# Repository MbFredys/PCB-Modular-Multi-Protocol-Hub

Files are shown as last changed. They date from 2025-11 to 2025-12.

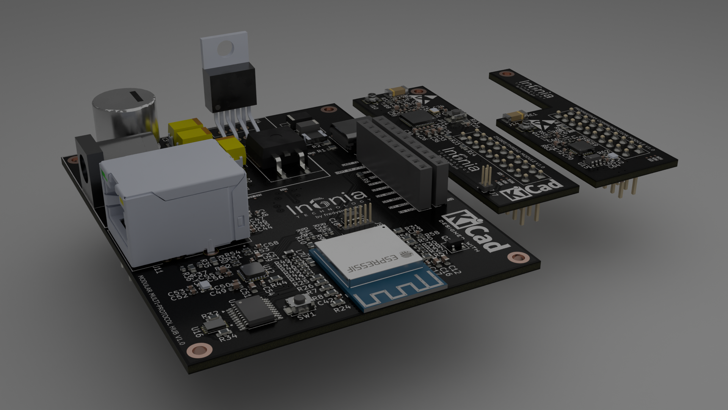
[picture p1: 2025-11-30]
Release/HUB-3D.png

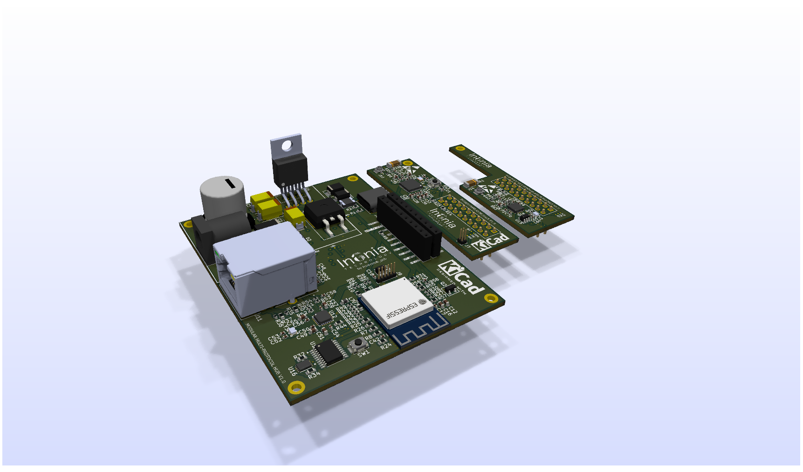
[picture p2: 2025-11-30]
Release/Hub3-pro.png

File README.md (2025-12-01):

# ⚡ Universal Smart-Home Modular Hub  


A compact, scalable, multi-protocol communication platform designed for modern smart homes.  
Built around a powerful **ESP32-S3**, with plug-in radio modules for Zigbee/Thread and Proprietary RF.  
Reliable power architecture, clean RF design, and automatic module detection.

---

## 🌍 Overview  
This system uses a **three-board modular hub architecture**:

### **1) Main Board – ESP32-S3 Controller**
Contains the ESP32-S3 with native **Wi-Fi + Bluetooth LE**, full power management, Ethernet support, and the universal expansion bus.

### **2) Zigbee/Thread Module – EFR32MG24**
A dedicated 2.4 GHz radio module supporting **Zigbee**, **Thread**, and **Matter over Thread** with a high-efficiency antenna.

### **3) Proprietary RF Module – nRF24L01+**
A flexible low-power 2.4 GHz module for **custom protocols**, legacy devices, and private links.

⚠️ **Only one expansion module is active at a time.**  
The **Main Board can run standalone** using Wi-Fi and BLE even with no module attached.

---

## 🎯 Problem This Project Solves  
Most smart-home hubs are:

- Locked to one brand or protocol  
- Difficult to expand  
- Closed hardware  
- Not modifiable or repairable  
- Dependent on cloud services  
- Not designed for RF noise isolation  

This project solves these issues with a fully documented, open, modular, serviceable platform.

---

# 🚀 Main Features

---

## 🧠 Main Board – ESP32-S3 Core Controller  

### **Capabilities**
- Native Wi-Fi + BLE  
- USB programming  
- JTAG debugging  
- I²C bus for module identification  
- SPI bus shared with expansion modules  
- Presence-detect signal  
- Ethernet PHY  
- Local battery backup  
- Clean, isolated power rails  

### **Standalone Operation**
If no radio module is plugged in, the board still supports:

- Wi-Fi control  
- BLE provisioning  
- Local automation  
- OTA updates  

---

## 📡 Zigbee / Thread / Matter Module – EFR32MG24  

### **Capabilities**
- Zigbee 3.0  
- Thread 1.3  
- Matter over Thread  
- High-efficiency chip antenna or external u.FL  
- SPI + IRQ communication  
- Local low-noise LDO  
- EEPROM with module ID  
- Hardware reset & enable control  
- SWD header for development  

### **Why a Separate Board?**
- RF noise isolation  
- Easy upgrades  
- Thermal and EMI improvements  
- Lower main-board complexity  

---

## 📡 Proprietary RF Module – nRF24L01+  

### **Capabilities**
- 2.4 GHz bidirectional transceiver  
- SPI interface  
- IRQ line  
- CE line for TX/RX control  
- Local LDO for clean RF power  
- On-board EEPROM for identification  

### **Why It Exists**
- Legacy systems  
- Private, encrypted links  
- Ultra-low-power sensors  
- Custom protocols  

---

# 🔋 Power Architecture

### **Main Board**
- 12 V input  
- Step-down to 5 V  
- 3.3 V LDO for logic  
- Local LDOs for each RF module  
- Battery charger & backup  
- Inrush, surge, ESD protection  
- Proper decoupling everywhere  

### **Radio Modules**
- Dedicated LDO  
- Ferrite-bead power filtering  
- Enable pin for power control  
- RF-clean power domain  

---

# 🧩 Automatic Module Identification (EEPROM)

Every expansion module includes a **24AA02E48 EEPROM** that stores:

- Unique EUI-48  
- Module type ID  

The ESP32 reads the EEPROM via I²C on boot and:

1. Identifies the module type  
2. Powers only the selected module  
3. Loads the appropriate firmware configuration  

---

# 🛡️ Reliability & Safety

- TVS on power rails  
- ESD protection on connectors  
- Solid ground planes  
- RF-clean routing  
- Ferrite-bead domain separation  
- Reverse-polarity protection  
- Controlled RF impedance paths  

---

# 🧭 Why This Architecture Is Better

- **Fully modular** — plug-in radio modules  
- **Upgradable** — replace modules anytime  
- **Main board works standalone**  
- **Automatic detection** via EEPROM  
- **Clean RF design** with isolated power  
- **Open hardware**  
- **Supports Wi-Fi, BLE, Zigbee, Thread, Matter, Proprietary RF**  
- **Future-proof** platform  
- **Easy to manufacture & repair**  

---

# 🛠️ Usage

1. Power the Main Board with 12 V  
2. Plug in a Zigbee or Proprietary RF module  
3. Firmware reads the module EEPROM  
4. Selected module is powered via EN_LDO  
5. ESP32 configures SPI/I²C pins  
6. Start using the hub via Wi-Fi, BLE, or RF  

---

# 🚀 Getting Started

1. Download design files  
2. Open schematic and PCB in KiCad  
3. Review:
   - Power sections  
   - Module connector  
   - RF networks  
   - Decoupling and filtering  
4. Manufacture PCBs  
5. Assembly order:
   1. Power stage  
   2. ESP32-S3 main board  
   3. Expansion connectors  
   4. RF module components  
   5. Antennas  
6. Flash the ESP32-S3 via USB  
7. Flash EFR32 module via SWD (if needed)  
8. Test and integrate with your smart-home backend  

---

# 🪪 License  
This project is licensed under the CERN Open Hardware Licence Version 2 - Weakly Reciprocal (CERN-OHL-W-2.0).
See the [CERN-OHL-W-2.0 ↗](https://gitlab.com/ohwr/project/cernohl/-/wikis/uploads/82b567f43ce515395f7ddbfbad7a8806/cern_ohl_w_v2.txt) file for more information.

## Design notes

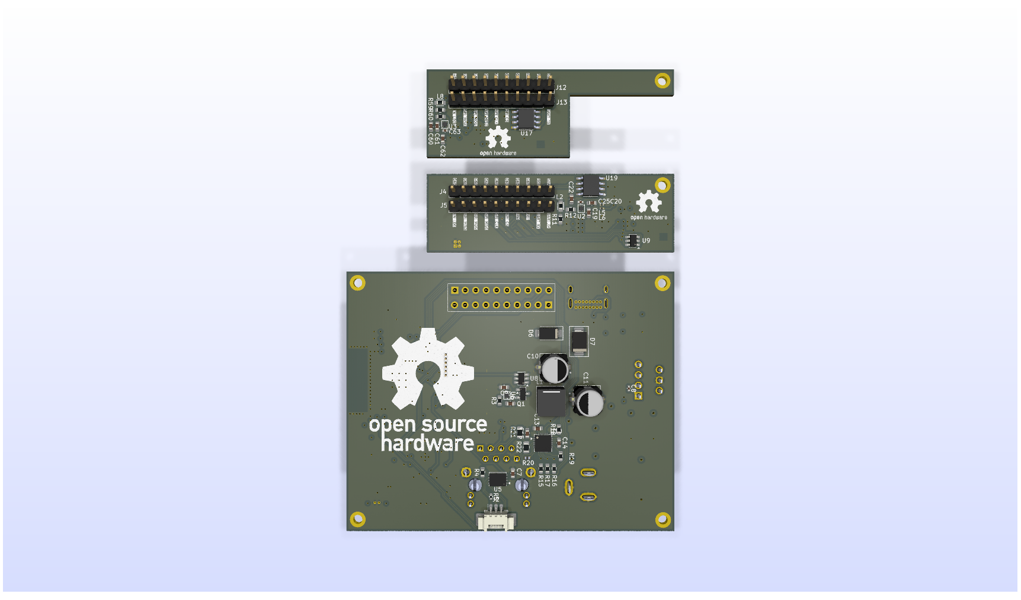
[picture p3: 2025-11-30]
Release/Hub2.png

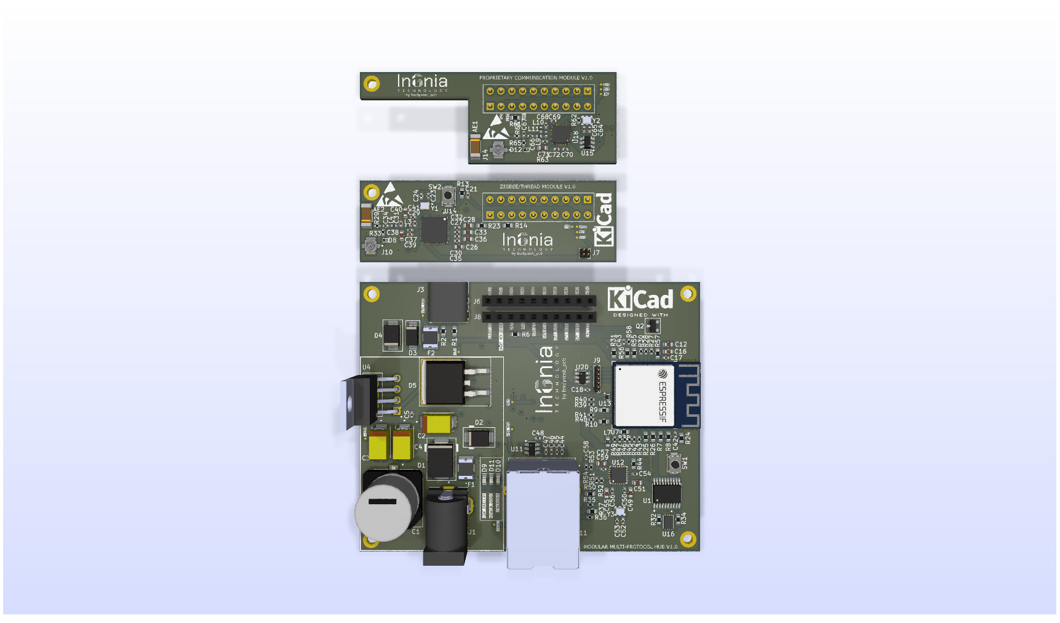
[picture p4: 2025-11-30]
Release/Hub1.png

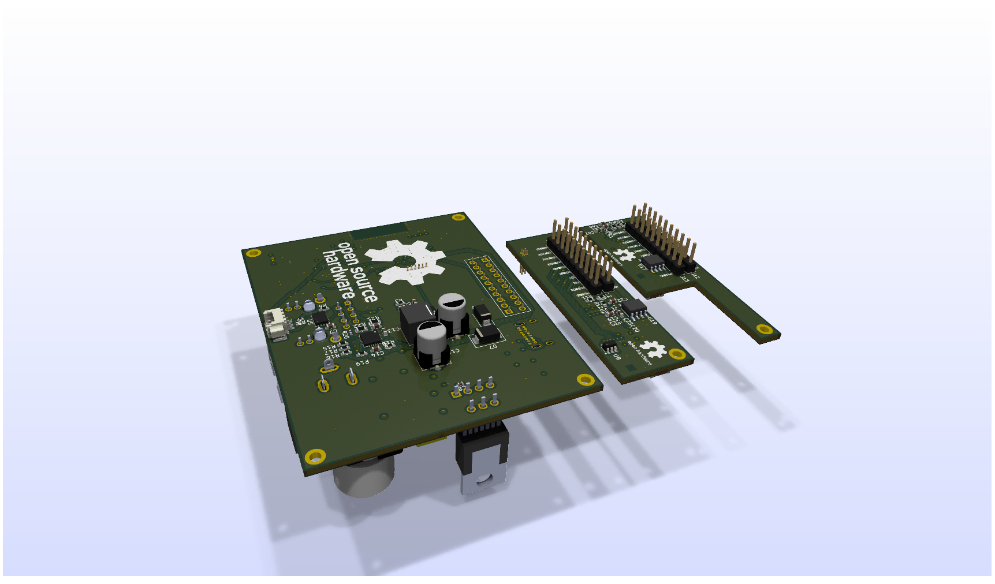
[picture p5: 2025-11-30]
Release/Hub4-pro.png

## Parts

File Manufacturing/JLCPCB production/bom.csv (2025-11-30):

Designator | Footprint | Quantity | Value | LCSC Part #
_6, _5, _4, _3, _2, |  | 6
+12V, +5V, +5V SYS, +5V USB, +VBAT, 3V3_3, 3V3_2, 3V3, GND_2, GND, IRQ_2, IRQ, NRST | TestPoint-0.5mm | 13 | 0.5mm
AE1, AE2 | ANT_2450AT42A100E_JOT | 2 | 2450AT42A100E | C2917719
C1 | CAP_EEVFK1E102Q | 1 | 1000uF | C178725
C10, C11 | CAP_EEEFNE181XUV | 2 | 180uF | C540948
C12, C51 | 0603 | 2 | 10uF | C48579265
C13, C16, C20, C22, C26, C28, C33, C36, C38, C49, C55, C57, C6, C61, C62, C7, C9 | 0603 | 17 | 1uF | C15849
C14, C15 | 0603 | 2 | 4.7uF | C1705
C17, C18, C21, C25, C27, C30, C32, C42, C43, C48, C54, C58, C63 | 0402 | 13 | 0.1uF | C48579249
C19, C60 | 0603 | 2 | 10uF | C15849
C2, C3, C4 | CAPPM7343X310N | 3 | 15uF | C382110
C23, C24, C44, C45, C46, C47, C52, C53 | 0402 | 8 | 10pF | C106199
C29 | 0402 | 1 | 2.3pF | C2220993
C31 | 0402 | 1 | 1.6pF | C161311
C34, C41 | 0402 | 2 | 18pF | C106202
C35, C69, C71 | 0402 | 3 | 10nF | CL05B103KB5NNNC
C37 | 0402 | 1 | 0.47uF | C92361
C39 | 0402 | 1 | 120pF | C106996
C40 | 0603 | 1 | 2.2uF | C48579298
C5 | 0402 | 1 | 0.47uF | C471404
C50, C59 | 0402 | 2 | 470pF | C76971
C56 | 0402 | 1 | 470pF
C64, C65 | 0402 | 2 | 22pF | C76960
C66 | 0402 | 1 | 1.5pF | C76901
C67 | 0402 | 1 | 1pF | C76898
C68, C70 | 0402 | 2 | 33nF | C7419416
C72 | 0402 | 1 | 1nF | C77018
C8 | 0402 | 1 | 0.01uF | C5137480
D1 | D_SMC | 1 | SS54 | C22452
D10, D11, D9 | 0603 | 3 | LEDs | C19171301
D12, D8 | D_SOD-923 | 2 | ESD9B3.3ST5G | C96512
D2 | D_SMB | 1 | SMBJ12A | C151251
D3, D6 | D_SMA | 2 | SS14 | C2837270
D4, D7 | D_SMB_TVS | 2 | SMBJ5.0CA | C5331095
D5 | TO-263-2_TabPin1 | 1 | MBRB735 | C6604203
F1, F2 | FUSE_1812L05060_LTF | 2 | PTC_FUSE | C163516
J1 | MPD_EJ503A | 1 | CON_12VDC_IN | C3095117
J10, J14 | LINX_CONMHF1-SMD-G-T | 2 | CONMHF1 | C22442695
J11 | ABRACON_ARJM11D7-009-AB-EW2 | 1 | ARJM11D7-009-AB-EW2 | C3179097
J12, J13 | PinHeader_1x10_P2.54mm_Vertical | 2 | PINHD
J2 | Molex_PicoBlade_53261-0371_1x03-1MP_P1.25mm_Horizontal | 1 | Conn_BAT | C293630
J3 | USB_C_Receptacle_GCT_USB4085 | 1 | Conn_USB_C | C7095263
J4, J5 | PinHeader_1x10_P2.54mm_Vertical | 2 | PINHD | C492409
J6, J8 | PinSocket_1x10_P2.54mm_Vertical | 2 | PINHD | C5444407
J7 | PinHeader_2x02_P1.00mm_Vertical | 1 | PINHD | C225517
J9 | PinHeader_1x06_P1.00mm_Vertical | 1 | JTAG | C52016393
L1 | IND_XAL6060-223MEB | 1 | 22uH | C475917
L10 | 0402 | 1 | 8.2nH | C84404
L11 | 0402 | 1 | 2.7nH | C162541
L2, L8 | R_0603 | 2 | FerriteBead_0603_1.5A | C2442094
L3 | 0402 | 1 | 2.5nH | C237342
L4 | 0402 | 1 | 1.7nH | C237342
L5, L6 | 0201 | 2 | FerriteBead_0603_1.5A | C97850
L7 | 0603 | 1 | FerriteBead | C14709
L9 | 0402 | 1 | 3.9nH | C98062
Q1 | SOT-23 | 1 | FDN340P | C75469
Q2 | SOT-23 | 1 | BC817 | C609806
R1, R2 | 0603 | 2 | 5.1k | C2907114
R10, R12, R13, R14, R24, R37, R4, R44, R55, R56, R57, R60, R8, R9 | 0603 | 14 | 10k | C2906982
R11, R3, R59, R6 | 0603 | 4 | 100k | C2906980
R15, R16, R17, R18, R19, R7 | 0603 | 6 | 470k | C2930293
R20 | THRMC1005X55N | 1 | 10k | C17294780
R21 | 0805 | 1 | 330k | C2907257
R22 | 0805 | 1 | 110k | C2907221
R23, R31 | 0603 | 2 | 1K | C49196685
R25, R26, R32, R34 | 0603 | 4 | 4.7k | C2907034
R27, R28, R30 | 0402 | 3 | 22 | C2929994
R29, R33, R64, R65 | 0402 | 4 | 0 | C106231
R38 | 0603 | 1 | 2.2k | C114662
R39, R40, R41, R42, R43, R45, R46, R47, R48, R49 | 0402 | 10 | 33 | C2906868
R5, R58 | 0402 | 2 | 100 | C2906860
R50 | 0603 | 1 | 12.1k | C2930059
R51, R52, R53, R54 | 0402 | 4 | 50 | C853312
R61 | 0603 | 1 | 10k
R62 | 0402 | 1 | 1M | C138033
R63 | 0603 | 1 | 22k | C2907015
SW1, SW2 | SW_Push_SPST_NO_Alps_SKRK | 2 | uC_Reset | C115357
U1 | TSSOP-20_4.4x6.5mm_P0.65mm | 1 | TCA9544A | C2674619
U10 | QFN-20-1EP_4x4mm_P0.5mm_EP2.5x2.5mm | 1 | MCP73871 | C5121473
U11 | SOT-23-6 | 1 | WE-TVS-824015043 | 824015043
U12 | LAN8720A | 1 | LAN8720A | C17146
U13 | Texas_DRT-3 | 1 | TPD2EUSB30A | C94934
U14 | XCVR_EFR32MG24B310F1536IM48-B | 1 | EFR32MG24B310F1536IM48-B | C6033379
U15, U20, U9 | SOT-23-6 | 3 | WE-TVS-824015043
U16 | SON50P200X300X60-9N | 1 | ATECC608A-MAHDA-T | C4749250
U17, U19 | SOIC127P600X175-8N | 2 | 24AA02E48-I_SN | C81475
U18 | QFN50P400X400X95-21N | 1 | NRF24L01 | C7015539
U2, U3, U6 | Texas_X2SON-4_1x1mm_P0.65mm | 3 | TPS7A20xxxDQN | C2866482
U4 | TO127P1041X469X2199-7N | 1 | LM2678T-ADJ | C95178
U5 | WDFN-8-1EP_4x3mm_P0.65mm_EP2.4x1.8mm | 1 | LC709203FQH-01TWG | C152311
U7 | ESP32-MINI | 1 | ESP32-S3-MINI-1 | C2913206
U8 | TSOT-23-6 | 1 | LTC4412xS6 | C514442
Y1 | XTAL_ECS-390-CDX-1932 | 1 | 39MHz | C19858547
Y2 | Crystal_SMD_2.0x1.6mm | 1 | 16MHz | C1985805
Y3 | Crystal_SMD_2.0x1.6mm | 1 | 25MHz | C1985948

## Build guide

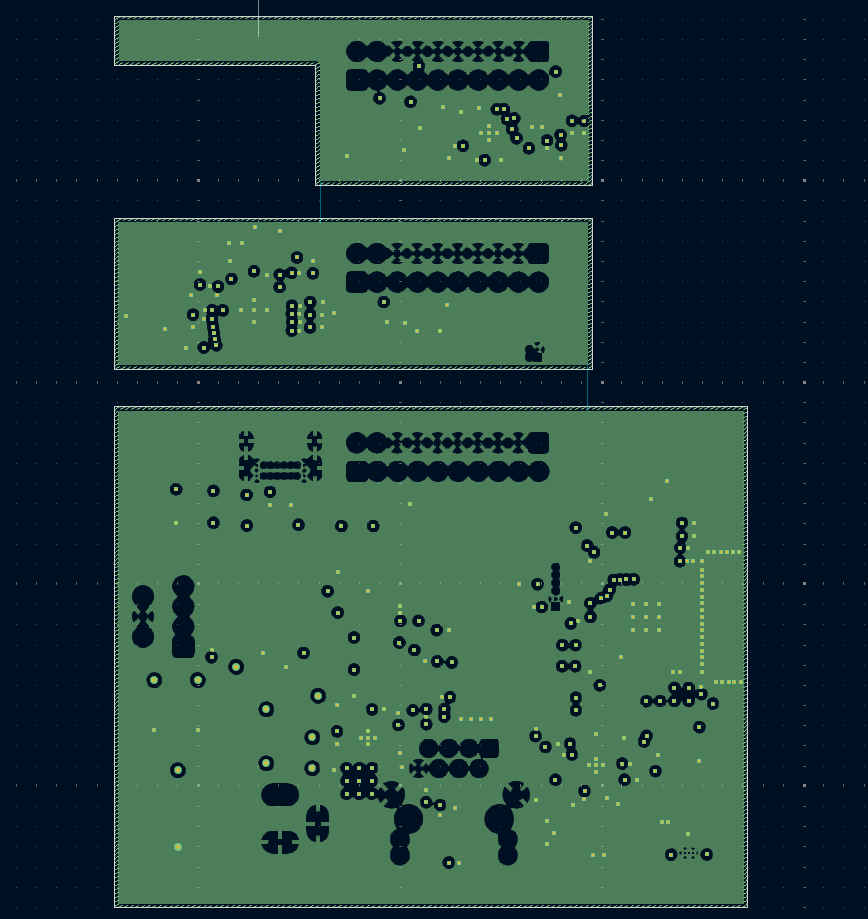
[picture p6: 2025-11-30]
Manufacturing/2nd Layer.png

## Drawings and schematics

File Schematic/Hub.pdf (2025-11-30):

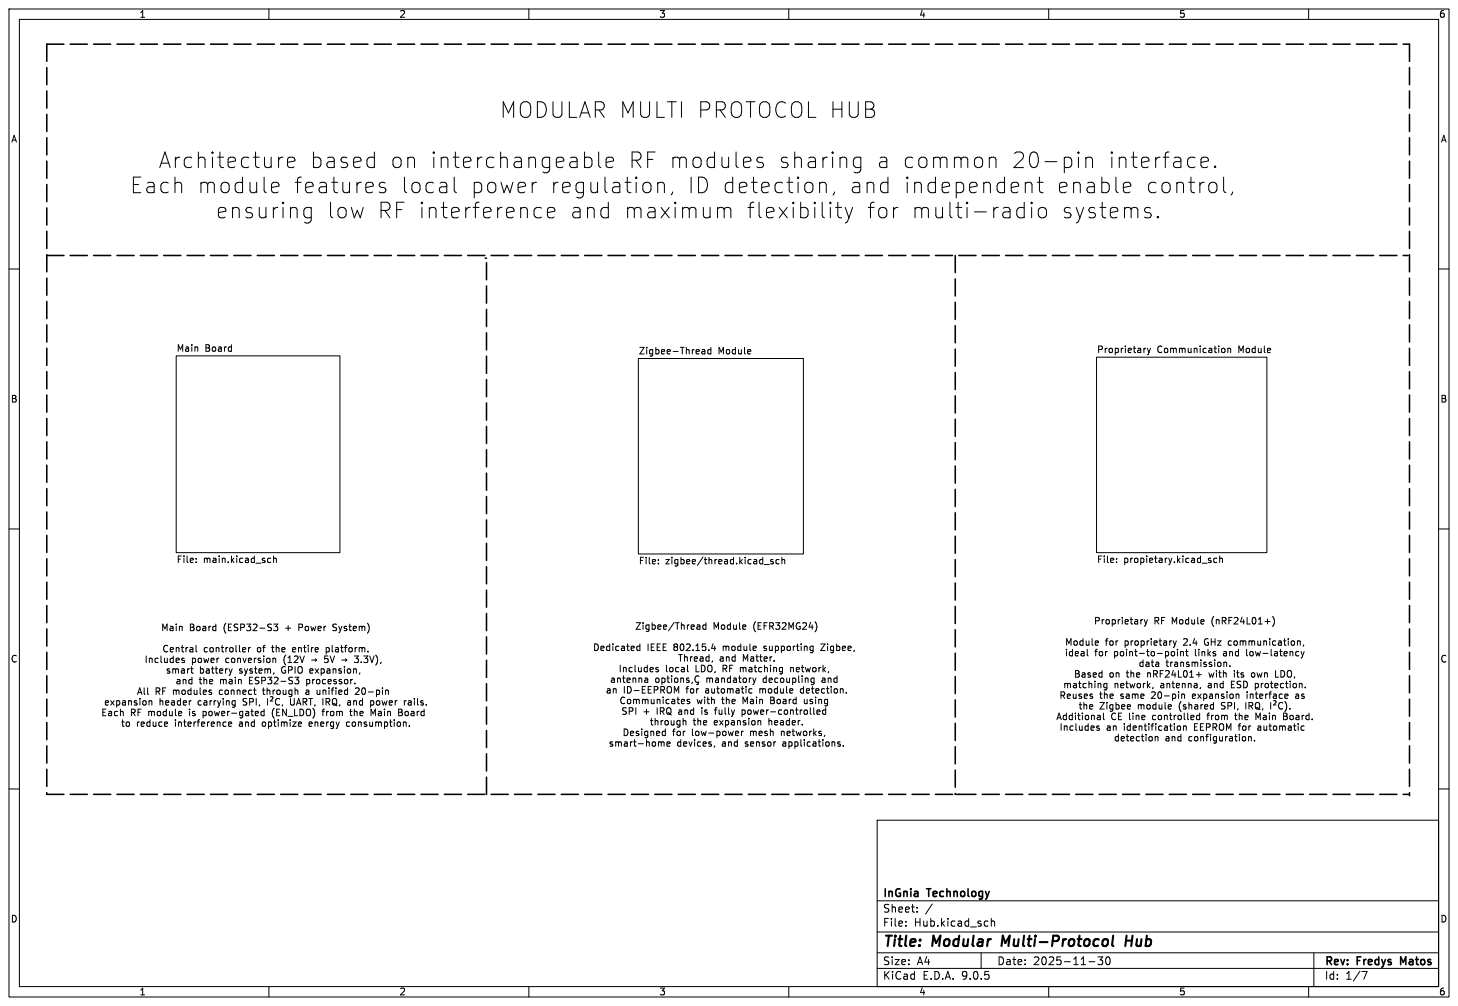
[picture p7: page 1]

MODULAR MULTI PROTOCOL HUB

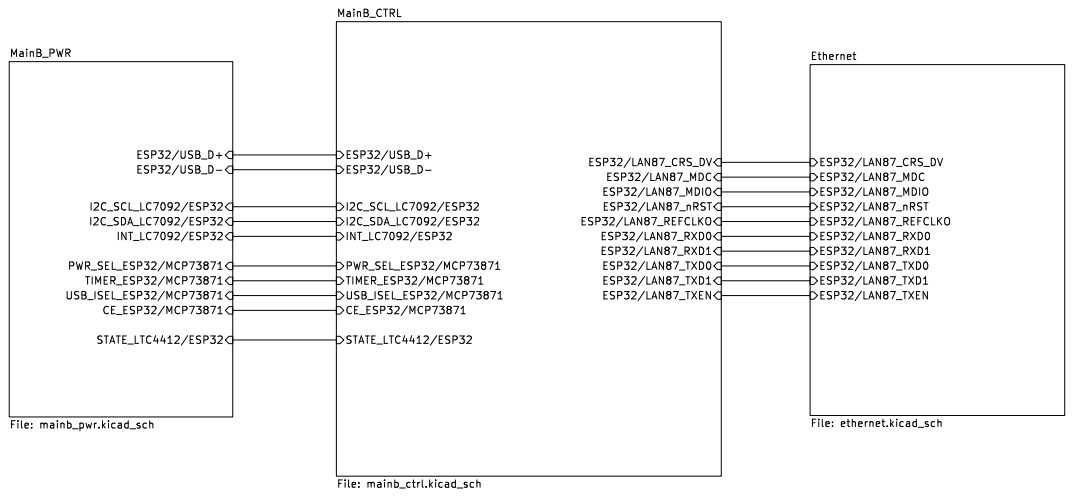
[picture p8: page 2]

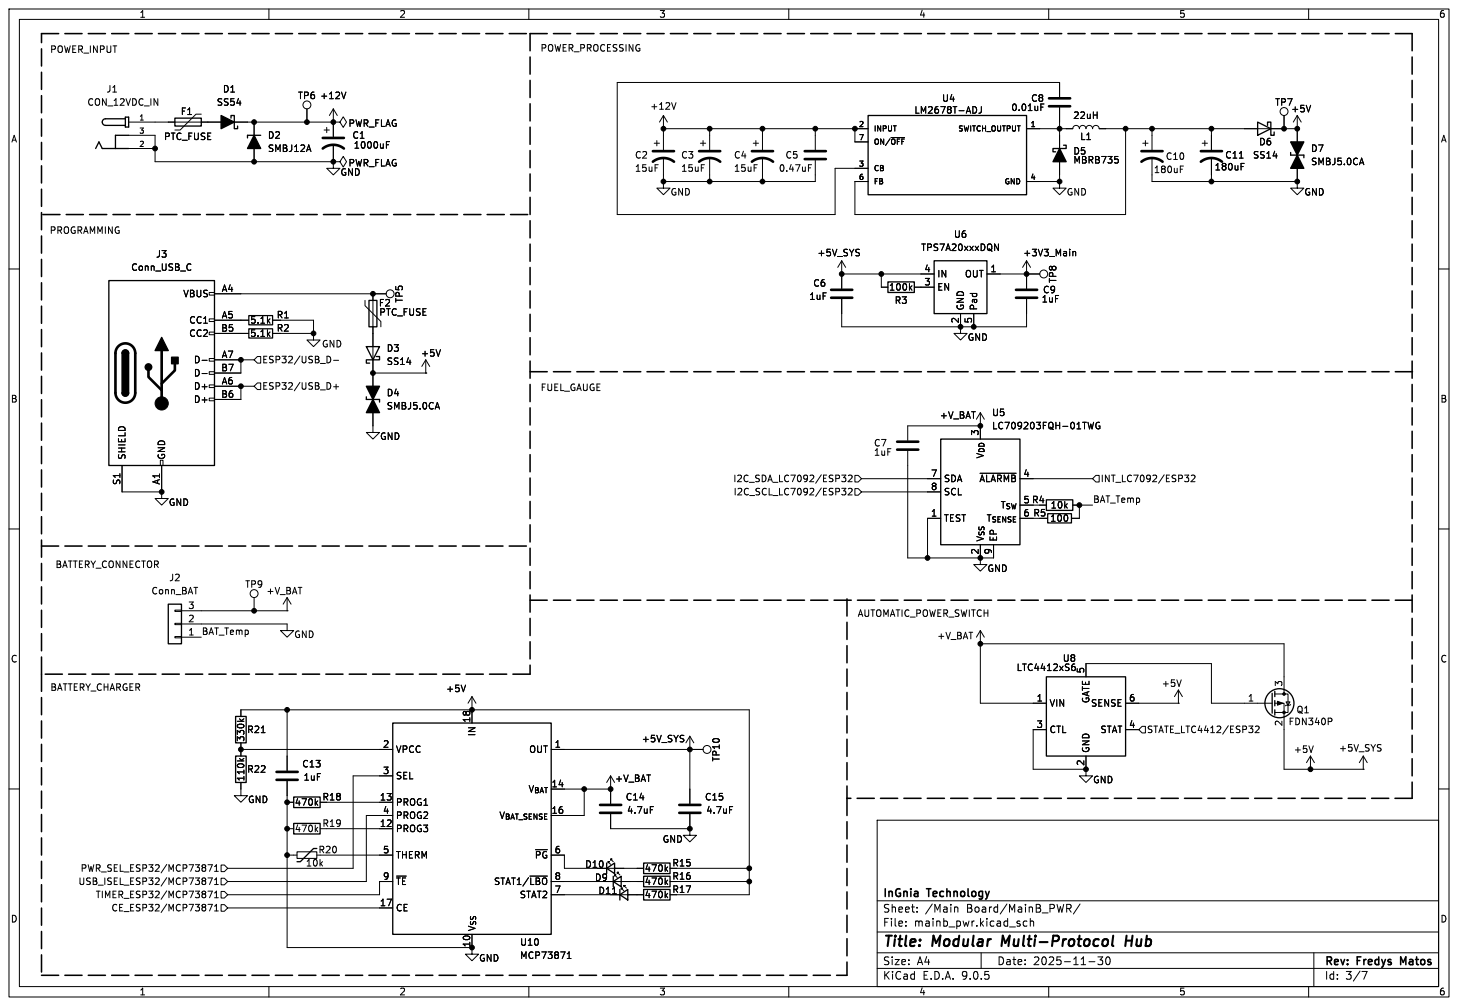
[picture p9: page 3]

2 SENSE 6 STAT 4 TP10+5V_SYS GND GND

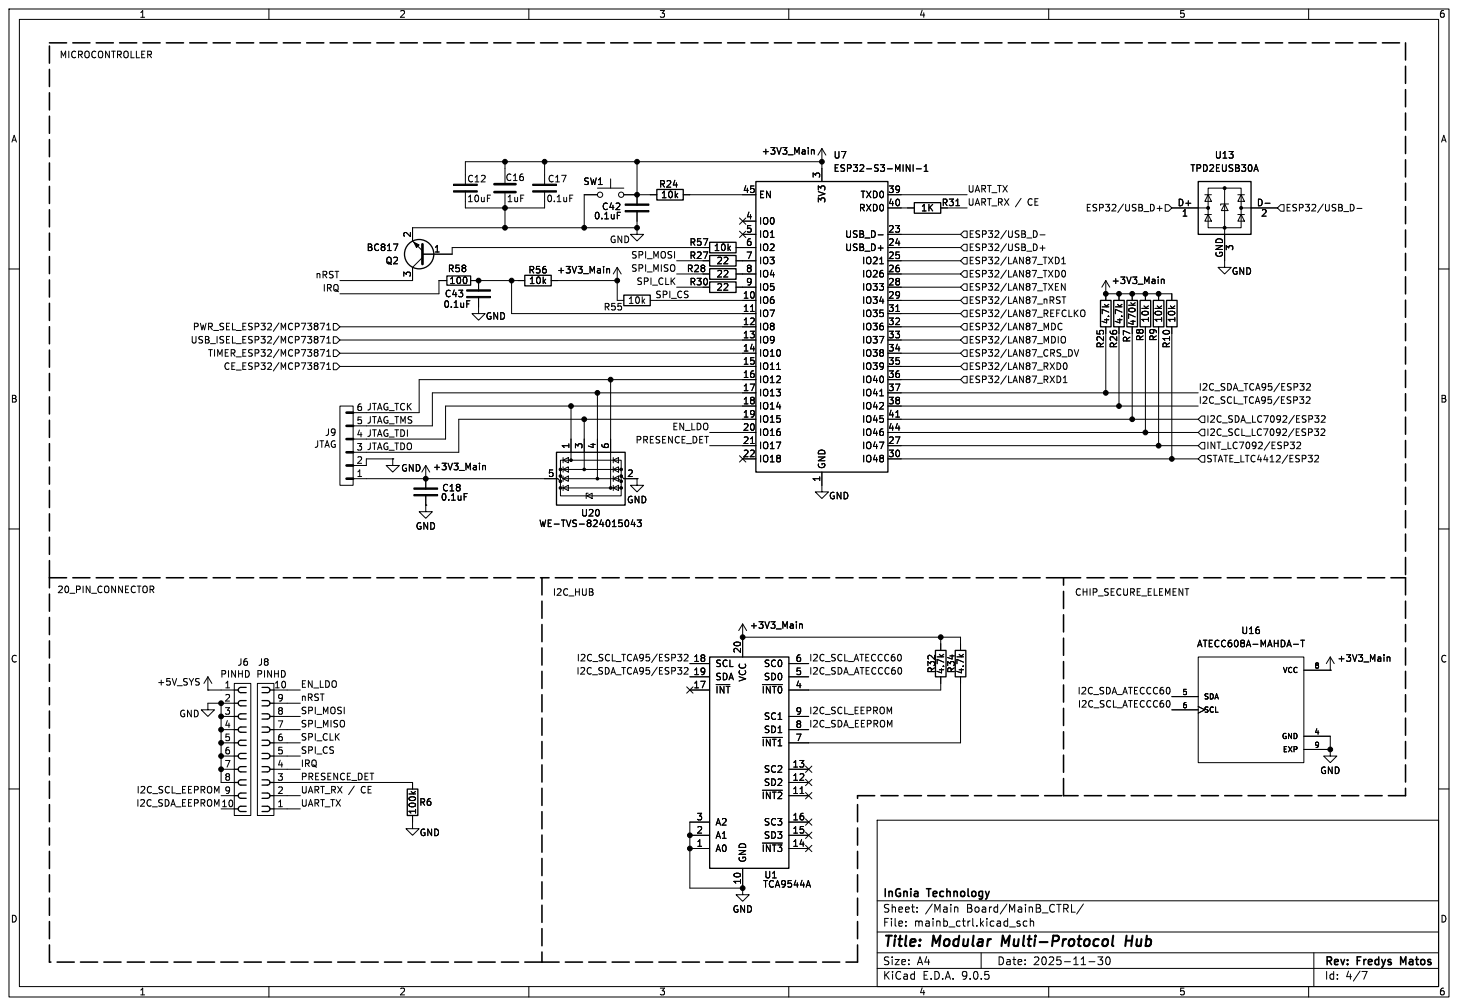
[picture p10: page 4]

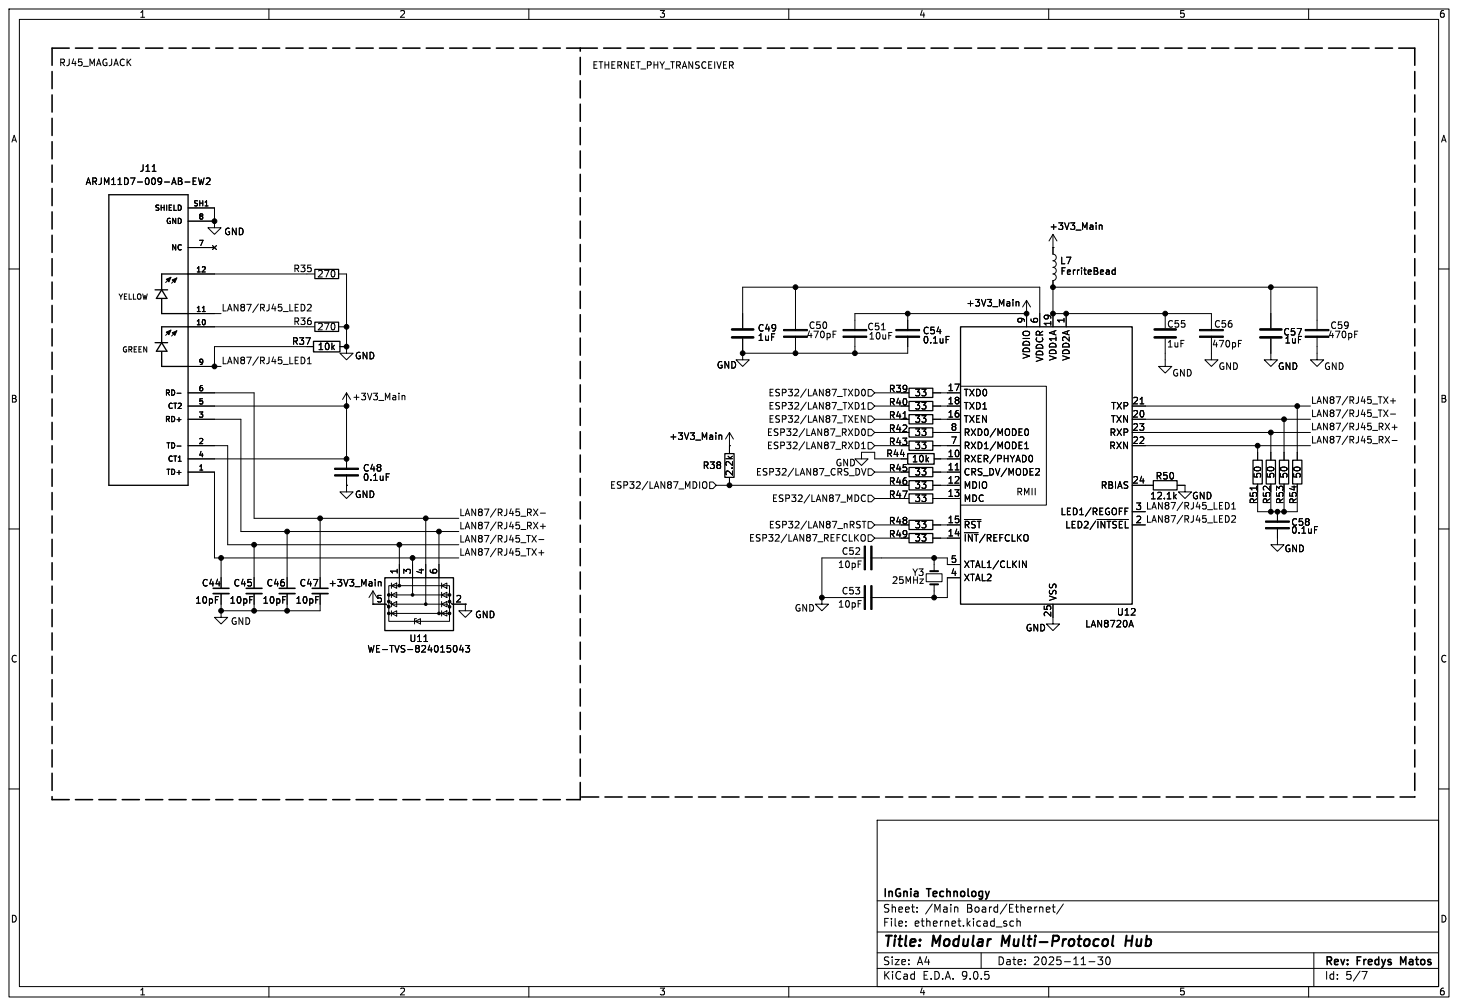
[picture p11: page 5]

1 TXP 21 TXN 20 RXP 23 RXN 22 RBIAS 24

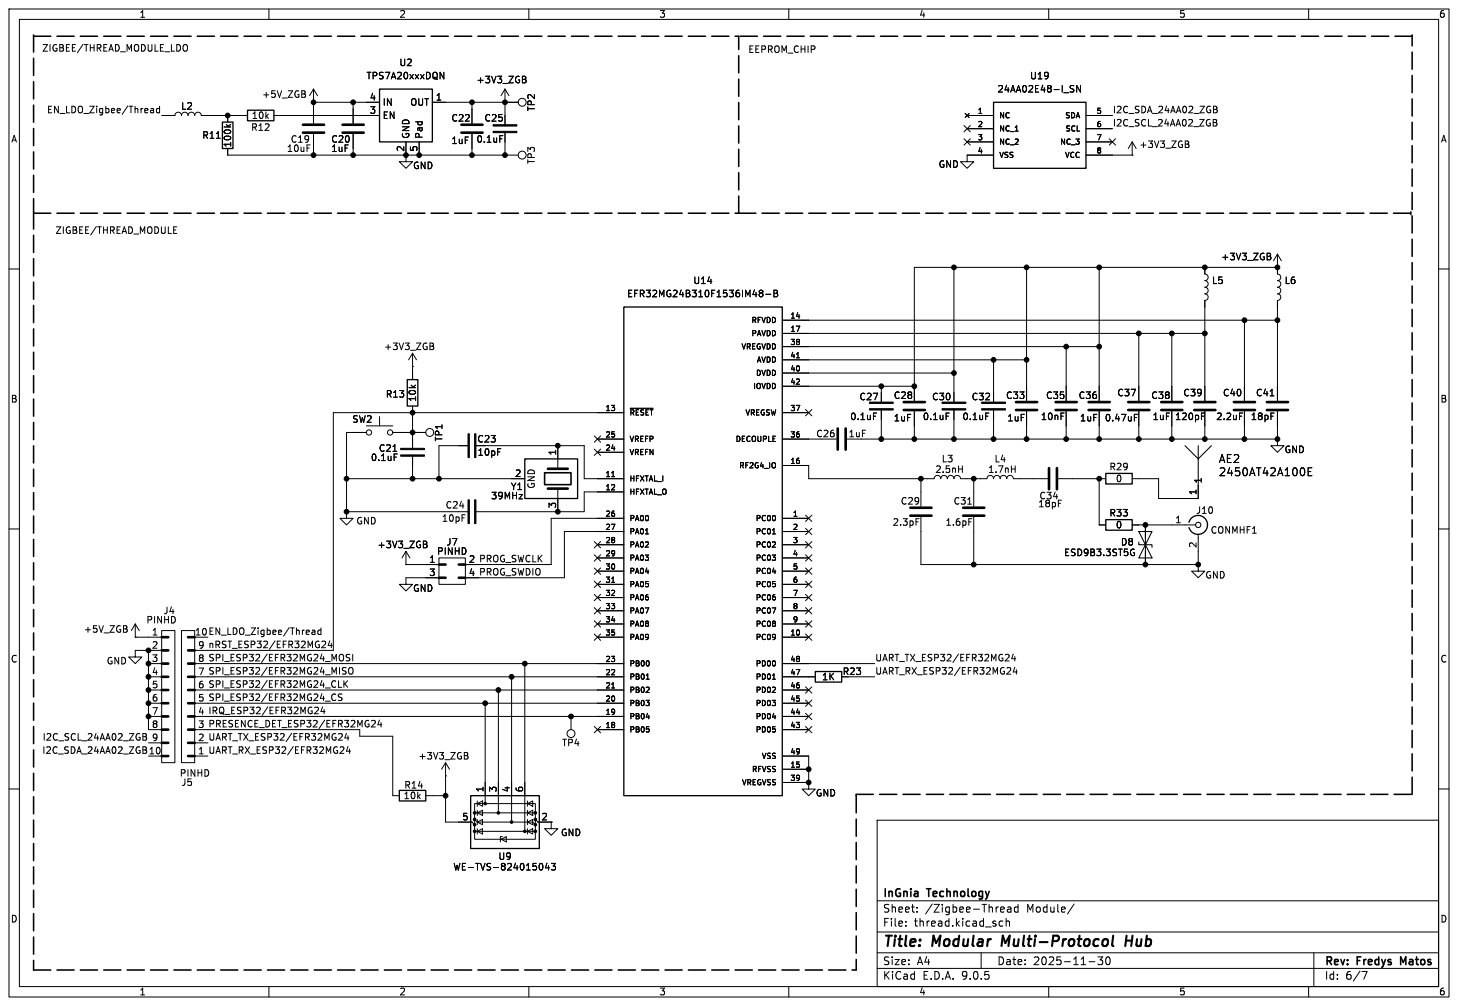
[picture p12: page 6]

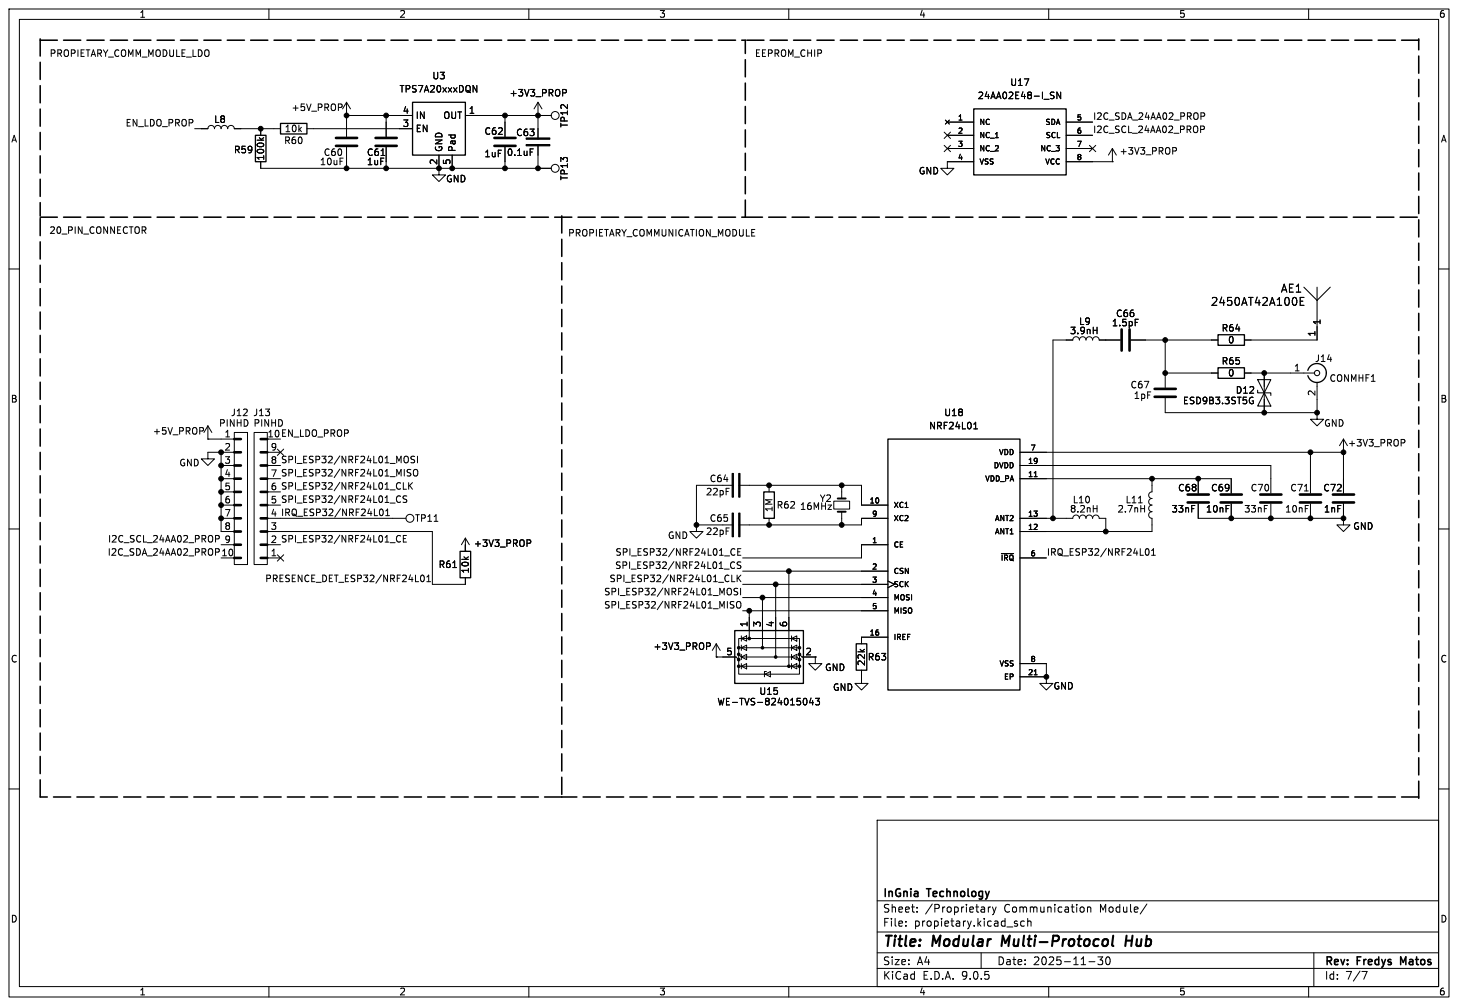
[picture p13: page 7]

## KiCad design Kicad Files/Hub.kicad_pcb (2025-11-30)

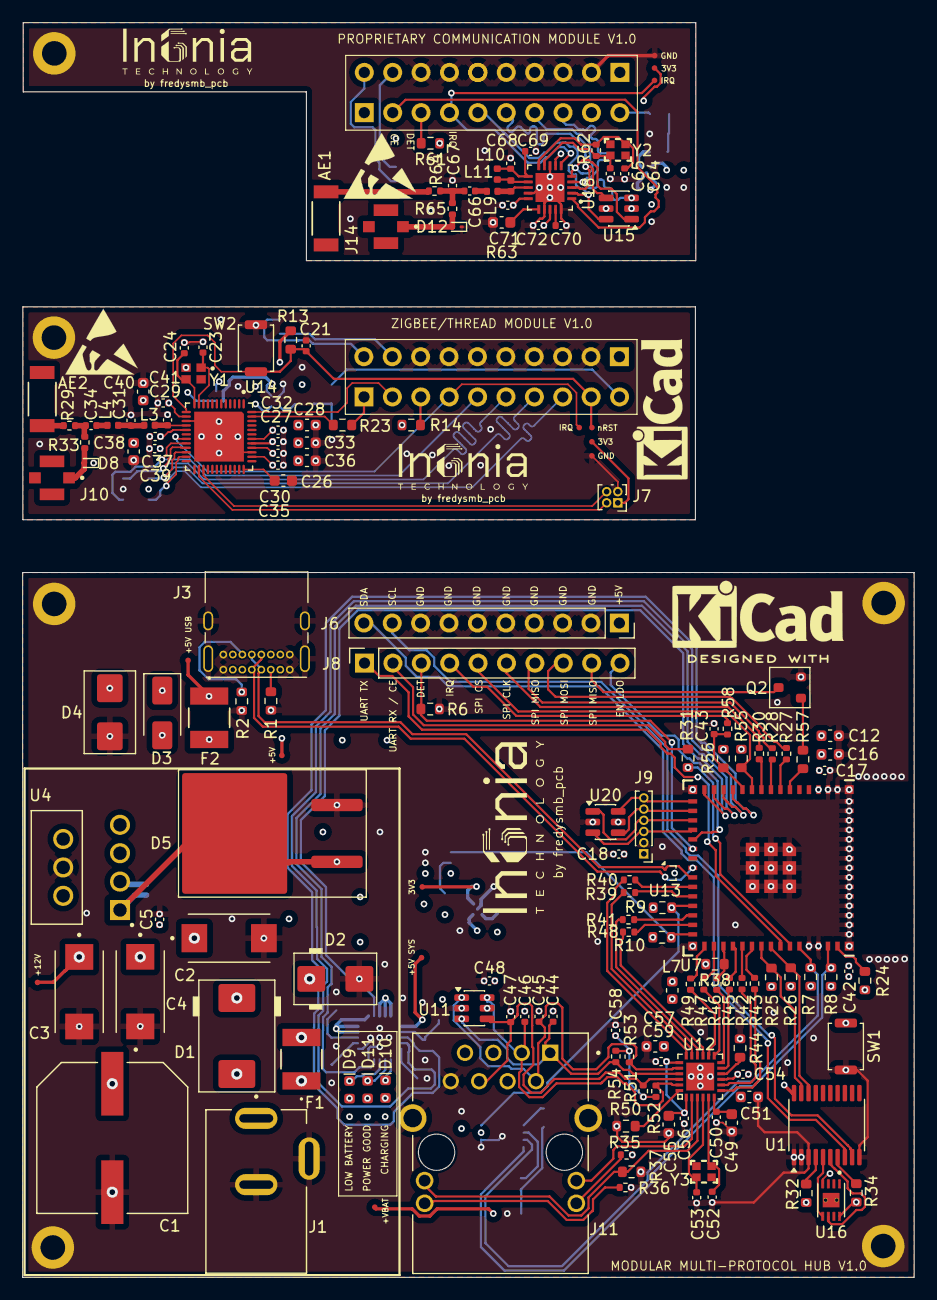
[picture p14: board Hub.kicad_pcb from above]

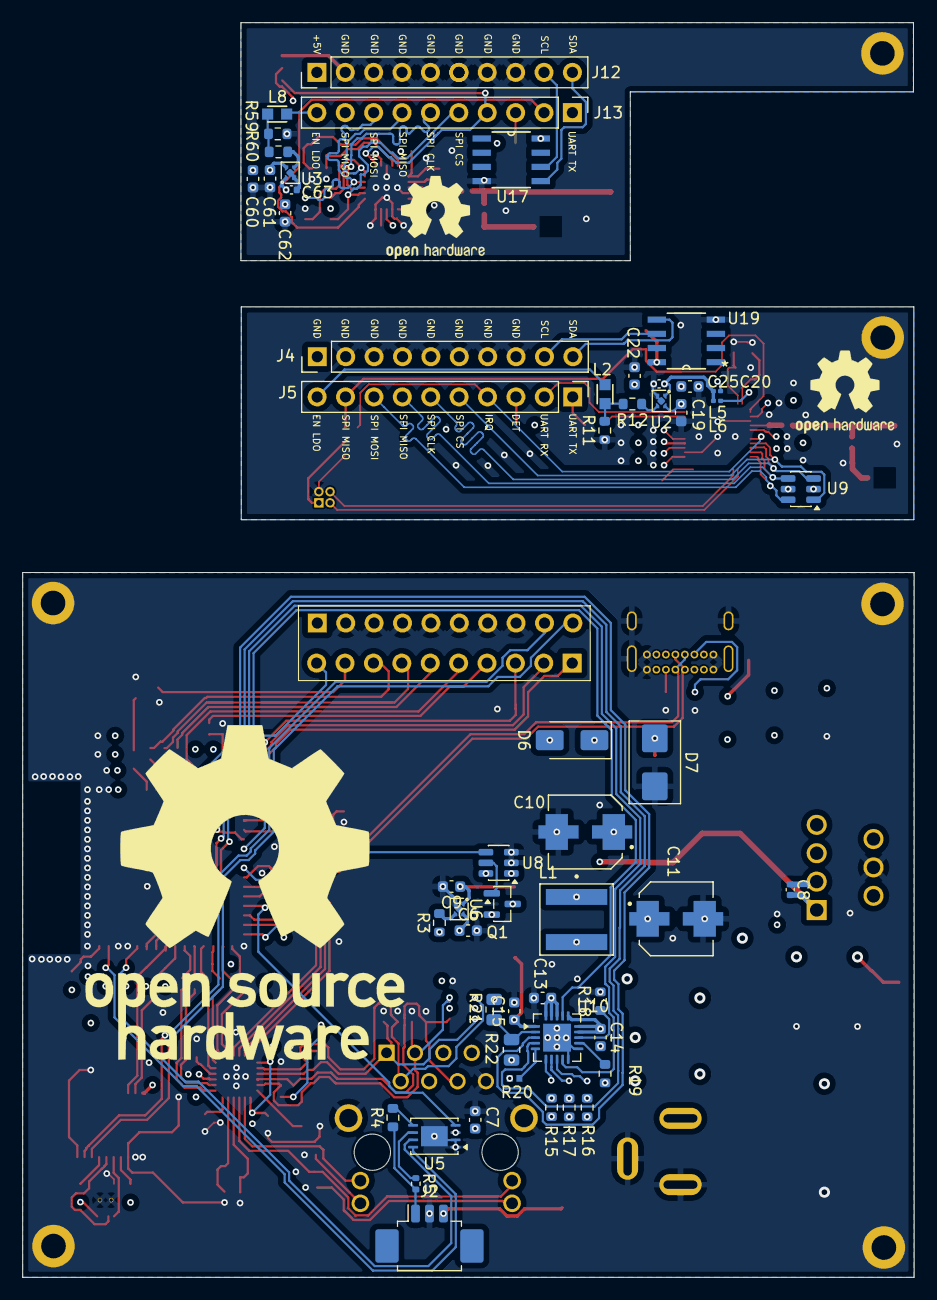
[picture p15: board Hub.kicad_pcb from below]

Board: 4 copper layers, 79.7 x 112.2 mm, 218 parts (54 on the bottom side), 159 nets.

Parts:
3V3, 3V3#2, 3V3#3: 0.5mm; TestPoint-0.5mm
+5V, +5V SYS, +5V USB, +12V: 0.5mm; TestPoint-0.5mm
+VBAT: 0.5mm; TestPoint-0.5mm
AE1, AE2: 2450AT42A100E; ANT_2450AT42A100E_JOT
C1: 1000uF; CAP_EEVFK1E102Q
C2, C3, C4: 15uF; CAPPM7343X310N
C5, C37: 0.47uF; C_0402_1005Metric
C6, C7, C9, C13, C16, C20, C22, C26, C28, C33, C36, C38, C49, C55, C57, C61, C62: 1uF; C_0603_1608Metric
C8: 0.01uF; C_0402_1005Metric
C10, C11: 180uF; CAP_EEEFNE181XUV
C12, C19, C51, C60: 10uF; C_0603_1608Metric
C14, C15: 4.7uF; C_0603_1608Metric
C17, C18, C21, C25, C27, C30, C32, C42, C43, C48, C54, C58, C63: 0.1uF; C_0402_1005Metric
C23, C24, C44, C45, C46, C47, C52, C53: 10pF; C_0402_1005Metric
C29: 2.3pF; C_0402_1005Metric
C31: 1.6pF; C_0402_1005Metric
C34, C41: 18pF; C_0402_1005Metric
C35, C69, C71: 10nF; C_0402_1005Metric
C39: 120pF; C_0402_1005Metric
C40: 2.2uF; C_0603_1608Metric
C50, C56, C59: 470pF; C_0402_1005Metric
C64, C65: 22pF; C_0402_1005Metric
C66: 1.5pF; C_0402_1005Metric
C67: 1pF; C_0402_1005Metric
C68, C70: 33nF; C_0402_1005Metric
C72: 1nF; C_0402_1005Metric
D1: SS54; D_SMC
D2: SMBJ12A; D_SMB
D3, D6: SS14; D_SMA
D4, D7: SMBJ5.0CA; D_SMB_TVS
D5: MBRB735; TO-263-2_TabPin1
D8, D12: ESD9B3.3ST5G; D_SOD-923
D9, D10, D11: LEDs; LED_0603_1608Metric
F1, F2: PTC_FUSE; FUSE_1812L05060_LTF
GND: 0.5mm; TestPoint-0.5mm
GND#2: 0.5mm; TestPoint-0.5mm
IRQ: 0.5mm; TestPoint-0.5mm
IRQ#2: 0.5mm; TestPoint-0.5mm
J1: CON_12VDC_IN; MPD_EJ503A
J2: Conn_BAT; Molex_PicoBlade_53261-0371_1x03-1MP_P1.25mm_Horizontal
J3: Conn_USB_C; USB_C_Receptacle_GCT_USB4085
J4, J5, J12, J13: PINHD; PinHeader_1x10_P2.54mm_Vertical
J6, J8: PINHD; PinSocket_1x10_P2.54mm_Vertical
J7: PINHD; PinHeader_2x02_P1.00mm_Vertical
J9: JTAG; PinHeader_1x06_P1.00mm_Vertical
J10, J14: CONMHF1; LINX_CONMHF1-SMD-G-T
J11: ARJM11D7-009-AB-EW2; ABRACON_ARJM11D7-009-AB-EW2
L1: 22uH; IND_XAL6060-223MEB
L2, L8: FerriteBead_0603_1.5A; R_0603
L3: 2.5nH; L_0402_1005Metric
L4: 1.7nH; L_0402_1005Metric
L5, L6: FerriteBead_0603_1.5A; R_0201_0603Metric
L7: FerriteBead; L_0603_1608Metric
L9: 3.9nH; L_0402_1005Metric
L10: 8.2nH; L_0402_1005Metric
L11: 2.7nH; L_0402_1005Metric
Q1: FDN340P; SOT-23
Q2: BC817; SOT-23
R1, R2: 5.1k; R_0603_1608Metric
R3, R6, R11, R59: 100k; R_0603_1608Metric
R4, R8, R9, R10, R12, R13, R14, R24, R37, R44, R55, R56, R57, R60, R61: 10k; R_0603_1608Metric
R5, R58: 100; R_0402_1005Metric
R7, R15, R16, R17, R18, R19: 470k; R_0603_1608Metric
R20: 10k; THRMC1005X55N
R21: 330k; R_0805_2012Metric
R22: 110k; R_0805_2012Metric
R23, R31: 1K; R_0603_1608Metric
R25, R26, R32, R34: 4.7k; R_0603_1608Metric
R27, R28, R30: 22; R_0402_1005Metric
R29, R33, R64, R65: 0; R_0402_1005Metric
R35, R36: 270; R_0402_1005Metric
R38: 2.2k; R_0603_1608Metric
R39, R40, R41, R42, R43, R45, R46, R47, R48, R49: 33; R_0402_1005Metric
R50: 12.1k; R_0603_1608Metric
R51, R52, R53, R54: 50; R_0402_1005Metric
R62: 1M; R_0402_1005Metric
R63: 22k; C_0603_1608Metric
SW1, SW2: uC_Reset; SW_Push_SPST_NO_Alps_SKRK
U1: TCA9544A; TSSOP-20_4.4x6.5mm_P0.65mm
U2, U3, U6: TPS7A20xxxDQN; Texas_X2SON-4_1x1mm_P0.65mm
U4: LM2678T-ADJ; TO127P1041X469X2199-7N
U5: LC709203FQH-01TWG; WDFN-8-1EP_4x3mm_P0.65mm_EP2.4x1.8mm
U7: ESP32-S3-MINI-1; ESP32-MINI
U8: LTC4412xS6; TSOT-23-6
U9, U11, U15, U20: WE-TVS-824015043; SOT-23-6
U10: MCP73871; QFN-20-1EP_4x4mm_P0.5mm_EP2.5x2.5mm
U12: LAN8720A
U13: TPD2EUSB30A; Texas_DRT-3
U14: EFR32MG24B310F1536IM48-B; XCVR_EFR32MG24B310F1536IM48-B
U16: ATECC608A-MAHDA-T; SON50P200X300X60-9N
U17, U19: 24AA02E48-I_SN; SOIC127P600X175-8N
U18: NRF24L01; QFN50P400X400X95-21N
Y1: 39MHz; XTAL_ECS-390-CDX-1932
Y2: 16MHz; Crystal_SMD_2.0x1.6mm
Y3: 25MHz; Crystal_SMD_2.0x1.6mm
nRST: 0.5mm; TestPoint-0.5mm

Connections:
+3V3_Main: 3V3#3.1, C9.1, C12.2, C16.1, C17.2, C18.2, C42.2, C48.2, C51.2, C54.2, J9.1, J11.4 (CT1), J11.5 (CT2), L7.1, R7.1, R8.1, R9.1, R10.1, R24.2, R25.1, R26.1, R32.1, R34.1, R38.2, R55.2, R56.2, SW1.2, U1.20 (VCC), U6.1 (OUT), U7.3 (3V3), U11.5 (VBUS), U12.9 (VDDIO), U16.8 (VCC), U20.5 (VBUS)
+3V3_PROP: 3V3.1, C62.1, C63.2, C71.2, C72.2, R61.1, U3.1 (OUT), U15.5 (VBUS), U17.8 (VCC), U18.7 (VDD), U18.15 (VDD), U18.18 (VDD)
+3V3_ZGB: 3V3#2.1, C22.1, C25.2, C27.2, C28.1, C30.2, C32.2, C33.1, C35.2, C36.1, J7.1, L5.1, L6.1, R13.1, R14.1, U2.1 (OUT), U9.5 (VBUS), U14.38 (VREGVDD), U14.40 (DVDD), U14.41 (AVDD), U14.42 (IOVDD), U19.8 (VCC)
+5V: +5V.1, +5V SYS.1, C6.1, C13.1, C15.1, D3.1 (K), D4.2 (A), D6.1 (K), D7.2 (A), J6.1, Q1.2 (S), R3.1, R15.1, R16.1, R17.1, R21.1, U6.4 (IN), U8.6 (SENSE), U10.1 (OUT), U10.18 (IN), U10.19 (IN), U10.20 (OUT)
+5V_PROP: C60.2, C61.1, J12.1, U3.4 (IN)
+5V_ZGB: C19.2, C20.1, J4.1, U2.4 (IN)
+12V: +12V.1, C1.1, C2.1, C3.1, C4.1, C5.1, D1.1 (K), D2.1 (K), U4.2 (INPUT), U4.7 (ON/~OFF)
+V_BAT: +VBAT.1, C7.1, C14.1, J2.3, Q1.3 (D), U5.3 (V_{DD}), U8.1 (VIN), U10.14 (V_{BAT}), U10.15 (V_{BAT}), U10.16 (V_{BAT_SENSE})
/Main Board/Ethernet/ESP32/LAN87_CRS_DV: R45.1, U7.34 (IO38)
/Main Board/Ethernet/ESP32/LAN87_MDC: R47.1, U7.32 (IO36)
/Main Board/Ethernet/ESP32/LAN87_MDIO: R38.1, R46.1, U7.33 (IO37)
/Main Board/Ethernet/ESP32/LAN87_REFCLKO: R49.1, U7.31 (IO35)
/Main Board/Ethernet/ESP32/LAN87_RXD0: R42.1, U7.35 (IO39)
/Main Board/Ethernet/ESP32/LAN87_RXD1: R43.1, U7.36 (IO40)
/Main Board/Ethernet/ESP32/LAN87_TXD0: R39.1, U7.26 (IO26)
/Main Board/Ethernet/ESP32/LAN87_TXD1: R40.1, U7.25 (IO21)
/Main Board/Ethernet/ESP32/LAN87_TXEN: R41.1, U7.28 (IO33)
/Main Board/Ethernet/ESP32/LAN87_nRST: R48.1, U7.29 (IO34)
/Main Board/Ethernet/LAN87/RJ45_LED1: J11.9, R37.2, U12.3 (LED1/REGOFF)
/Main Board/Ethernet/LAN87/RJ45_LED2: J11.11, U12.2 (LED2/~INTSEL)
/Main Board/Ethernet/LAN87/RJ45_RX+: C46.1, J11.3 (RD+), R52.2, U11.6 (I/O4), U12.23 (RXP)
/Main Board/Ethernet/LAN87/RJ45_RX-: C47.1, J11.6 (RD-), R51.2, U11.4 (I/O3), U12.22 (RXN)
/Main Board/Ethernet/LAN87/RJ45_TX+: C44.1, J11.1 (TD+), R54.2, U11.3 (I/O2), U12.21 (TXP)
/Main Board/Ethernet/LAN87/RJ45_TX-: C45.1, J11.2 (TD-), R53.2, U11.1 (I/O1), U12.20 (TXN)
/Main Board/MainB_CTRL/CE_ESP32/MCP73871: U7.15 (IO11), U10.17 (CE)
/Main Board/MainB_CTRL/EN_LDO: J8.10, U7.20 (IO16)
/Main Board/MainB_CTRL/ESP32/USB_D+: J3.A6 (D+), J3.B6 (D+), U7.24 (USB_D+), U13.1 (D+)
/Main Board/MainB_CTRL/ESP32/USB_D-: J3.A7 (D-), J3.B7 (D-), U7.23 (USB_D-), U13.2 (D-)
/Main Board/MainB_CTRL/I2C_SCL_ATECCC60: U1.6 (SC0), U16.6 (SCL)
/Main Board/MainB_CTRL/I2C_SCL_EEPROM: J6.9, U1.9 (SC1)
/Main Board/MainB_CTRL/I2C_SCL_LC7092/ESP32: R8.2, U5.8 (SCL), U7.44 (IO46)
/Main Board/MainB_CTRL/I2C_SCL_TCA95/ESP32: R26.2, U1.18 (SCL), U7.38 (IO42)
/Main Board/MainB_CTRL/I2C_SDA_ATECCC60: U1.5 (SD0), U16.5 (SDA)
/Main Board/MainB_CTRL/I2C_SDA_EEPROM: J6.10, U1.8 (SD1)
/Main Board/MainB_CTRL/I2C_SDA_LC7092/ESP32: R7.2, U5.7 (SDA), U7.41 (IO45)
/Main Board/MainB_CTRL/I2C_SDA_TCA95/ESP32: R25.2, U1.19 (SDA), U7.37 (IO41)
/Main Board/MainB_CTRL/INT_LC7092/ESP32: R9.2, U5.4 (~ALARMB), U7.27 (IO47)
/Main Board/MainB_CTRL/IRQ: J8.4, R58.1
/Main Board/MainB_CTRL/JTAG_TCK: J9.6, U7.16 (IO12), U20.6 (I/O4)
/Main Board/MainB_CTRL/JTAG_TDI: J9.4, U7.18 (IO14), U20.1 (I/O1)
/Main Board/MainB_CTRL/JTAG_TDO: J9.3, U7.19 (IO15), U20.3 (I/O2)
/Main Board/MainB_CTRL/JTAG_TMS: J9.5, U7.17 (IO13), U20.4 (I/O3)
/Main Board/MainB_CTRL/PRESENCE_DET: J8.3, R6.2, U7.21 (IO17)
/Main Board/MainB_CTRL/PWR_SEL_ESP32/MCP73871: U7.12 (IO8), U10.3 (SEL)
/Main Board/MainB_CTRL/SPI_CLK: J8.6, R30.2
/Main Board/MainB_CTRL/SPI_CS: J8.5, R55.1, U7.10 (IO6)
/Main Board/MainB_CTRL/SPI_MISO: J8.7, R28.2
/Main Board/MainB_CTRL/SPI_MOSI: J8.8, R27.1
/Main Board/MainB_CTRL/STATE_LTC4412/ESP32: R10.2, U7.30 (IO48), U8.4 (STAT)
/Main Board/MainB_CTRL/TIMER_ESP32/MCP73871: U7.14 (IO10), U10.9 (~TE)
/Main Board/MainB_CTRL/UART_RX / CE: J8.2, R31.1
/Main Board/MainB_CTRL/UART_TX: J8.1, U7.39 (TXD0)
/Main Board/MainB_CTRL/USB_ISEL_ESP32/MCP73871: U7.13 (IO9), U10.4 (PROG2)
/Main Board/MainB_CTRL/nRST: J8.9, Q2.3 (C)
/Main Board/MainB_PWR/BAT_Temp: J2.1, R4.1, R5.2
/Proprietary Communication Module/EN_LDO_PROP: J13.10, L8.1
/Proprietary Communication Module/I2C_SCL_24AA02_PROP: J12.9, U17.6 (SCL)
/Proprietary Communication Module/I2C_SDA_24AA02_PROP: J12.10, U17.5 (SDA)
/Proprietary Communication Module/IRQ_ESP32/NRF24L01: IRQ#2.1, J13.4, U18.6 (~IRQ)
/Proprietary Communication Module/PRESENCE_DET_ESP32/NRF24L01: J13.3, R61.2
/Proprietary Communication Module/SPI_ESP32/NRF24L01_CE: J13.2, U18.1 (CE)
/Proprietary Communication Module/SPI_ESP32/NRF24L01_CLK: J13.6, U15.4 (I/O3), U18.3 (SCK)
/Proprietary Communication Module/SPI_ESP32/NRF24L01_CS: J13.5, U15.6 (I/O4), U18.2 (CSN)
/Proprietary Communication Module/SPI_ESP32/NRF24L01_MISO: J13.7, U15.1 (I/O1), U18.5 (MISO)
/Proprietary Communication Module/SPI_ESP32/NRF24L01_MOSI: J13.8, U15.3 (I/O2), U18.4 (MOSI)
/Zigbee-Thread Module/EN_LDO_Zigbee/Thread: J5.10, L2.1
/Zigbee-Thread Module/I2C_SCL_24AA02_ZGB: J4.9, U19.6 (SCL)
/Zigbee-Thread Module/I2C_SDA_24AA02_ZGB: J4.10, U19.5 (SDA)
/Zigbee-Thread Module/IRQ_ESP32/EFR32MG24: IRQ.1, J5.4, U14.19 (PB04)
/Zigbee-Thread Module/PRESENCE_DET_ESP32/EFR32MG24: J5.3, R14.2
/Zigbee-Thread Module/PROG_SWCLK: J7.2, U14.26 (PA00)
/Zigbee-Thread Module/PROG_SWDIO: J7.4, U14.27 (PA01)
/Zigbee-Thread Module/SPI_ESP32/EFR32MG24_CLK: J5.6, U9.3 (I/O2), U14.21 (PB02)
/Zigbee-Thread Module/SPI_ESP32/EFR32MG24_CS: J5.5, U9.1 (I/O1), U14.20 (PB03)
/Zigbee-Thread Module/SPI_ESP32/EFR32MG24_MISO: J5.7, U9.4 (I/O3), U14.22 (PB01)
/Zigbee-Thread Module/SPI_ESP32/EFR32MG24_MOSI: J5.8, U9.6 (I/O4), U14.23 (PB00)
/Zigbee-Thread Module/UART_RX_ESP32/EFR32MG24: J5.1, R23.1
/Zigbee-Thread Module/UART_TX_ESP32/EFR32MG24: J5.2, U14.48 (PD00)
/Zigbee-Thread Module/nRST_ESP32/EFR32MG24: C21.2, J5.9, R13.2, SW2.2, U14.13 (~RESET), nRST.1
GND: C1.2, C2.2, C3.2, C4.2, C5.2, C6.2, C7.2, C9.2, C10.2, C11.2, C12.1, C13.2, C14.2, C15.2, C16.2, C17.1, C18.1, C19.1, C20.2, C21.1, C22.2, C23.1, C24.1, C25.1, C26.1, C27.1, C28.2, C29.1, C30.1, C31.1, C32.1, C33.2, C35.1, C36.2, C37.1, C38.2, C39.1, C40.1, C41.1, C42.1, C43.1, C44.2, C45.2, C46.2, C47.2, C48.1, C49.2, C50.2, C51.1, C52.1, C53.1, C54.1, C55.2, C56.2, C57.2, C58.1, C59.2, C60.1, C61.2, C62.2, C63.1, C64.1, C65.1, C67.1, C68.1, C69.1, C70.1, C71.1, C72.1, D2.2 (A), D4.1 (K), D5.2 (A), D7.1 (K), D8.1 (A1), D12.1 (A1), GND.1, GND#2.1, J1.2, J1.3, J2.2, J3.A1 (GND), J3.A12 (GND), J3.B1 (GND), J3.B12 (GND), J3.S1 (SHIELD), J4.2, J4.3, J4.4, J4.5, J4.6, J4.7, J4.8, J6.2, J6.3, J6.4, J6.5, J6.6, J6.7, J6.8, J7.3, J9.2, J11.8 (GND), J11.SH1 (SHIELD), J11.SH2 (SHIELD), J12.2, J12.3, J12.4, J12.5, J12.6, J12.7, J12.8, Q2.2 (E), R1.2, R2.2, R6.1, R11.1, R18.2, R19.2, R20.1, R22.2, R35.2, R36.2, R37.1, R44.2, R50.1, R59.1, R63.1, SW1.1, SW2.1, U1.1 (A0), U1.2 (A1), U1.3 (A2), U1.10 (GND), U2.2 (GND), U2.5 (Pad), U3.2 (GND), U3.5 (Pad), U4.4 (GND), U5.1 (TEST), U5.2 (V_{SS}), U5.9 (EP), U6.2 (GND), U6.5 (Pad), U7.1 (GND), U7.2 (GND), U7.42 (GND), U7.43 (GND), U7.46 (GND), U7.47 (GND), U7.48 (GND), U7.49 (GND), U7.50 (GND), U7.51 (GND), U7.52 (GND), U7.53 (GND), U7.54 (GND), U7.55 (GND), U7.56 (GND), U7.57 (GND), U7.58 (GND), U7.59 (GND), U7.60 (GND), U7.61 (GND), U7.62 (GND), U7.63 (GND), U7.64 (GND), U7.65 (GND), U8.2 (GND), U8.3 (CTL), U9.2 (GND), U10.10 (V_{SS}), U10.11 (V_{SS}), U10.21 (V_{SS}), U11.2 (GND), U12.25 (VSS), U13.3 (GND), U14.15 (RFVSS), U14.39 (VREGVSS), U14.49 (VSS), U15.2 (GND), U16.4 (GND), U16.9 (EXP), U16.9_1 (EXP), U16.9_2 (EXP), U17.4 (VSS), U18.8 (VSS), U18.14 (VSS), U18.17 (VSS), U18.20 (VSS), U18.21 (EP), U19.4 (VSS), U20.2 (GND), Y1.2
unnamed: AE1.1, R64.2
unnamed: AE2.1, R29.2
unnamed: C31.2, L3.2, L4.1
unnamed: C34.1, R29.1, R33.1
unnamed: C34.2, L4.2
unnamed: C58.2, R51.1, R52.1, R53.1, R54.1
unnamed: C66.1, C67.2, R64.1, R65.1
unnamed: C66.2, L9.2
unnamed: D1.2 (A), F1.2
unnamed: D3.2 (A), F2.2
unnamed: C8.2, D5.1 (K), L1.1, U4.1 (SWITCH_OUTPUT)
unnamed: C10.1, C11.1, D6.2 (A), L1.2, U4.6 (FB)
unnamed: D8.2 (A2), J10.1 (In), R33.2
unnamed: D9.2 (A), R16.2
unnamed: D9.1 (K), U10.8 (STAT1/~LBO)
unnamed: D10.2 (A), R15.2
unnamed: D10.1 (K), U10.6 (~PG)
unnamed: D11.2 (A), R17.2
unnamed: D11.1 (K), U10.7 (STAT2)
unnamed: D12.2 (A2), J14.1 (In), R65.2
unnamed: F1.1, J1.1
unnamed: +5V USB.1, F2.1, J3.A4 (VBUS), J3.A9 (VBUS), J3.B4 (VBUS), J3.B9 (VBUS)
unnamed: J3.A5 (CC1), R1.1
unnamed: J3.B5 (CC2), R2.1
unnamed: J11.10, R36.1
unnamed: J11.12, R35.1
unnamed: L2.2, R11.2, R12.2
unnamed: L8.2, R59.2, R60.2
unnamed: Q1.1 (G), U8.5 (GATE)
unnamed: Q2.1 (B), R57.2
unnamed: R32.2, U1.4 (~INT0)
unnamed: R34.2, U1.7 (~INT1)
unnamed: R12.1, U2.3 (EN)
unnamed: R60.1, U3.3 (EN)
unnamed: C8.1, U4.3 (CB)
unnamed: R5.1, U5.6 (T_{SENSE})
unnamed: R4.2, U5.5 (T_{SW})
unnamed: R3.2, U6.3 (EN)
unnamed: R24.1, U7.45 (EN)
unnamed: R57.1, U7.6 (IO2)
unnamed: R27.2, U7.7 (IO3)
unnamed: R28.1, U7.8 (IO4)
unnamed: R30.1, U7.9 (IO5)
unnamed: C43.2, R56.1, R58.2, U7.11 (IO7)
unnamed: R31.2, U7.40 (RXD0)
unnamed: R18.1, U10.13 (PROG1)
unnamed: R19.1, U10.12 (PROG3)
unnamed: R20.2, U10.5 (THERM)
unnamed: R21.2, R22.1, U10.2 (VPCC)
unnamed: R45.2, U12.11 (CRS_DV/MODE2)
unnamed: R47.2, U12.13 (MDC)
unnamed: R46.2, U12.12 (MDIO)
unnamed: R50.2, U12.24 (RBIAS)
unnamed: R42.2, U12.8 (RXD0/MODE0)
unnamed: R43.2, U12.7 (RXD1/MODE1)
unnamed: R44.1, U12.10 (RXER/PHYAD0)
unnamed: R39.2, U12.17 (TXD0)
unnamed: R40.2, U12.18 (TXD1)
unnamed: R41.2, U12.16 (TXEN)
unnamed: C55.1, C56.1, C57.1, C59.1, L7.2, U12.1 (VDD2A), U12.19 (VDD1A)
unnamed: C49.1, C50.1, U12.6 (VDDCR)
unnamed: C52.2, U12.5 (XTAL1/CLKIN), Y3.1
unnamed: C53.2, U12.4 (XTAL2), Y3.2
unnamed: R49.2, U12.14 (~INT/REFCLKO)
unnamed: R48.2, U12.15 (~RST)
unnamed: C26.2, U14.36 (DECOUPLE)
unnamed: C23.2, U14.11 (HFXTAL_I), Y1.1
unnamed: C24.2, U14.12 (HFXTAL_O), Y1.3
unnamed: C37.2, C38.1, C39.2, L5.2, U14.17 (PAVDD)
unnamed: R23.2, U14.47 (PD01)
unnamed: C29.2, L3.1, U14.16 (RF2G4_IO)
unnamed: C40.2, C41.2, L6.2, U14.14 (RFVDD)
unnamed: L10.2, L11.1, U18.12 (ANT1)
unnamed: L9.1, L10.1, U18.13 (ANT2)
unnamed: C70.2, U18.19 (DVDD)
unnamed: R63.2, U18.16 (IREF)
unnamed: C68.2, C69.2, L11.2, U18.11 (VDD_PA)
unnamed: C64.2, R62.2, U18.10 (XC1), Y2.1
unnamed: C65.2, R62.1, U18.9 (XC2), Y2.2

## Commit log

2025-11-30 Create kicad
2025-11-30 Update schematic.md to add header

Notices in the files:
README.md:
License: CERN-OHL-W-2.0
